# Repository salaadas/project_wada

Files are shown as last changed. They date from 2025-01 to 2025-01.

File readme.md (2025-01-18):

# Project Wada

Although I love my HHKB Pro 2, sometimes I just want some arrow keys for gaming. This made me learn how to design a PCB and make it has a layout somewhat similar to the HHKB. I also realized that the Realforce RC1 kinda has the same layout as this keyboard too.

Anyways, here is the layout.

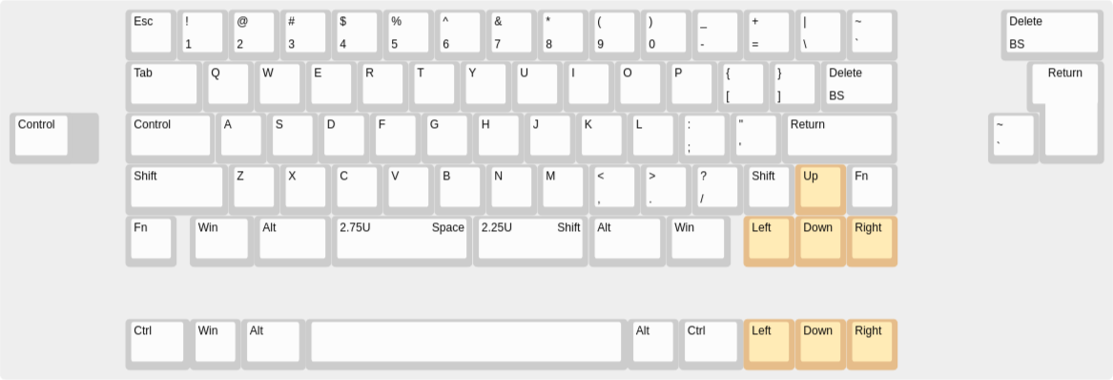
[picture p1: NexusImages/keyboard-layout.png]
keyboard layout


## Incomplete..... more to come after I finished!

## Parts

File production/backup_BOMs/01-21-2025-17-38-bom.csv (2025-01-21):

Designator | Footprint | Quantity | Value | LCSC Part #
BOOT_SW1, RESET_SW1 | SW_SPST_TL3342 | 2 | SW_SPST | C318884
C1, C10, C11, C9 | 603 | 4 | 1uF | C15849
C12, C13, C14, C15, C16, C17, C18, C19, C20, C23, C26, C29, C30, C31, C32, C33, C34, C35, C36, C37, C38, C39, C4, C40, C41, C42, C43, C44, C45, C46, C47, C5, C6, C7, C8 | 603 | 35 | 100nF | C14663
C2, C24, C27, C3 | 603 | 4 | 10uF | C19702
C21, C22 | 603 | 2 | 30pF | C1658
C25, C28 | CP_Elec_6.3x5.9 | 2 | 100uF | C134878
D1, D10, D11, D12, D13, D14, D15, D16, D17, D18, D19, D2, D20, D21, D22, D23, D24, D25, D26, D27, D28, D29, D3, D30, D31, D32, D33, D34, D35, D36, D37, D38, D39, D4, D40, D41, D42, D43, D44, D45, D46, D47, D48, D49, D5, D50, D51, D52, D53, D54, D55, D56, D57, D58, D59, D6, D60, D61, D62, D63, D64, D65, D66, D7, D8, D9 | D_SOD-123 | 66 | D_Small | C81598
F1 | 1206 | 1 | 500mA | C70076
J1 | USB_C_Receptacle_HRO_TYPE-C-31-M-12 | 1 | USB_C_Receptacle_USB2.0_16P | C165948
J2, J3 | JING 903-231A2031S10100 | 2 | USB_A | C42646
L1, L2, L3 | 603 | 3 | 220V @ 100MHz, 2A | C85832
LED1, LED10, LED11, LED12, LED13, LED14, LED15, LED16, LED2, LED3, LED4, LED5, LED6, LED7, LED8, LED9 | LED_SK6812MINI_HAND_SOLDER_3.5x3.5mm_P1.75mm | 16 | SK6812MINI | C2922787
R1, R2 | 402 | 2 | 5.1kR | C25905
R10, R11, R12, R14, R3, R4, R6, R7, R8, R9 | 603 | 10 | 10kR | C25804
R13 | 603 | 1 | 2.7kR | C13167
U1 | SOT-23 | 1 | XC6206PxxxMR | C5446
U2 | LQFP-48_7x7mm_P0.5mm | 1 | STM32F072C8T6 | C81720
U3 | SOIC-8_3.9x4.9mm_P1.27mm | 1 | MIC2026-2BN | C148072
U4 | LQFP-48_7x7mm_P0.5mm | 1 | FE1.1 | C28958
U5, U6, U7 | SOT-23-6-routable | 3 | SRV05-4 | C85364
U8 | SOT-23-5 | 1 | 74AHCT1G125 | C7484
Y1 | Crystal_SMD_3225-4pin_3.2x2.5mm | 1 | 12MHz | C9002

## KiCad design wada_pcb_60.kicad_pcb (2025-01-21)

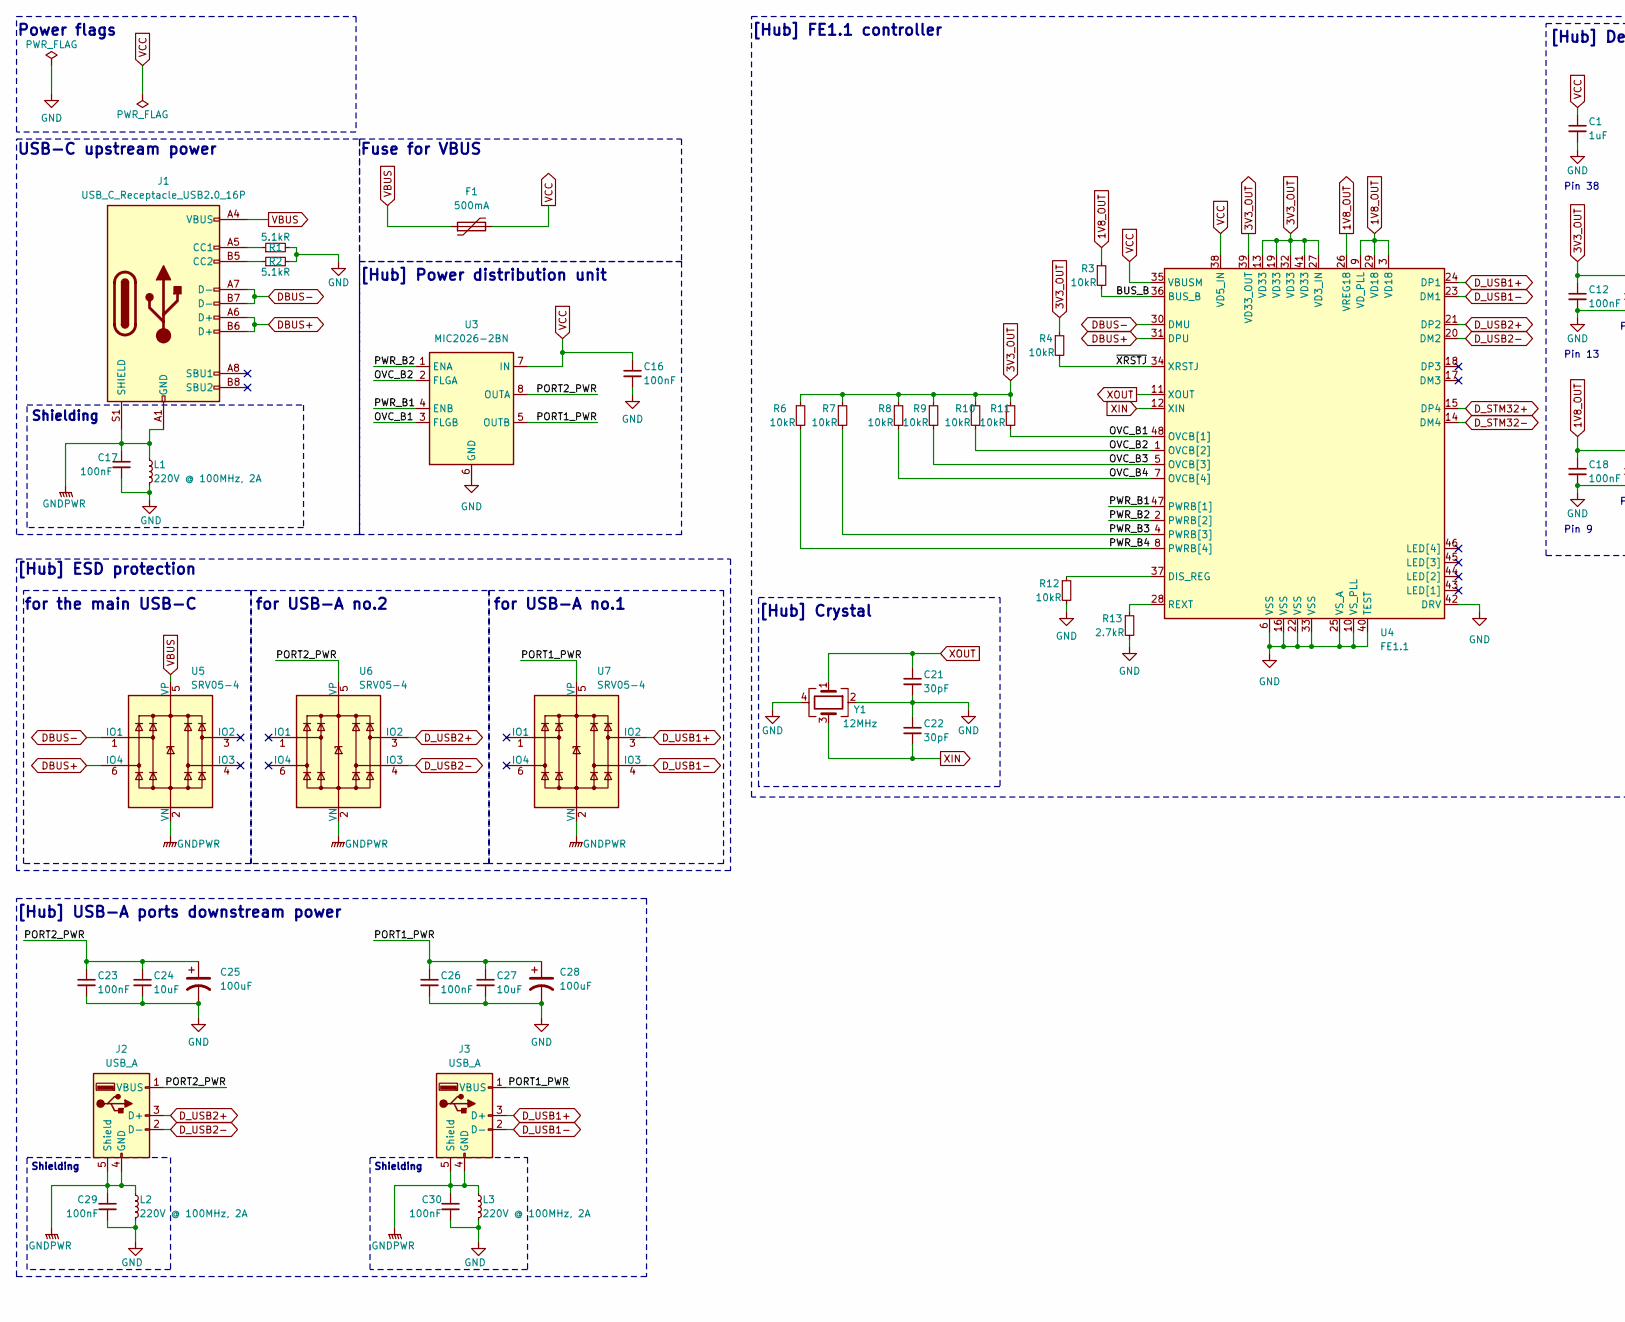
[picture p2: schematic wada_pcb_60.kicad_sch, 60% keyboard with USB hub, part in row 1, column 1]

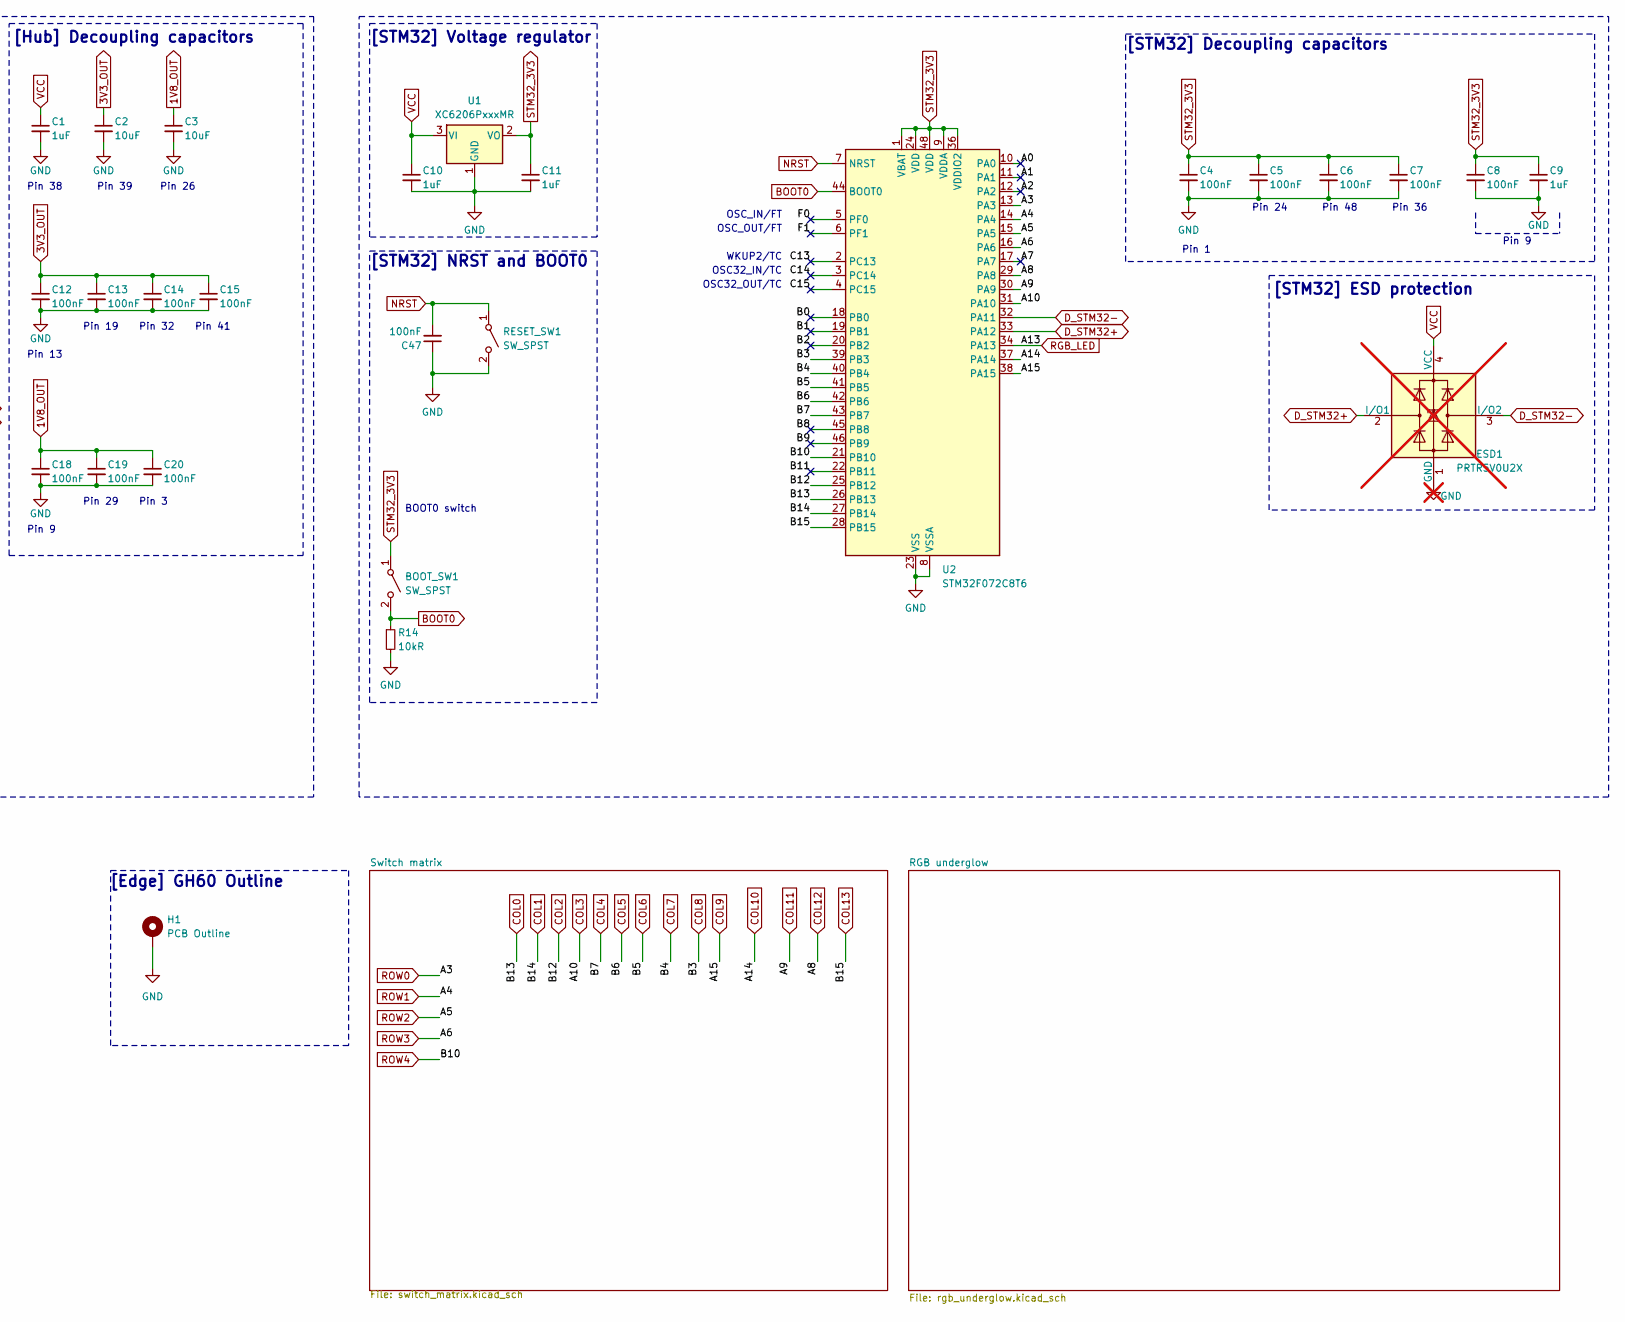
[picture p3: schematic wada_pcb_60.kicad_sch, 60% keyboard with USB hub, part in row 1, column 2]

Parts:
BOOT_SW1: SW_SPST; SW_SPST_TL3342
C1, C9, C10, C11: 1uF; C_0603_1608Metric
C2, C3, C24, C27: 10uF; C_0603_1608Metric
C4, C5, C6, C7, C8, C12, C13, C14, C15, C16, C17, C18, C19, C20, C23, C26, C29, C30, C47: 100nF; C_0603_1608Metric
C21, C22: 30pF; C_0603_1608Metric
C25, C28: 100uF; CP_Elec_6.3x5.9
ESD1: PRTR5V0U2X; SOT-143; not fitted
F1: 500mA; Fuse_1206_3216Metric
H1: PCB Outline; GH60_outline_without_bottom_mounting
J1: USB_C_Receptacle_USB2.0_16P; USB_C_Receptacle_HRO_TYPE-C-31-M-12
J2, J3: USB_A; JING 903-231A2031S10100
L1, L2, L3: 220V @ 100MHz, 2A; L_0603_1608Metric
R1, R2: 5.1kR; R_0402_1005Metric
R3, R4, R6, R7, R8, R9, R10, R11, R12, R14: 10kR; R_0603_1608Metric
R13: 2.7kR; R_0603_1608Metric
RESET_SW1: SW_SPST; SW_SPST_TL3342
U1: XC6206PxxxMR; SOT-23
U2: STM32F072C8T6; LQFP-48_7x7mm_P0.5mm
U3: MIC2026-2BN; SOIC-8_3.9x4.9mm_P1.27mm
U4: FE1.1; LQFP-48_7x7mm_P0.5mm
U5, U6, U7: SRV05-4; SOT-23-6-routable
Y1: 12MHz; Crystal_SMD_3225-4pin_3.2x2.5mm

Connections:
1V8_OUT: C3.1, C18.1, C19.1, C20.1, R3.1, U4.3 (VD18), U4.9 (VD_PLL), U4.26 (VREG18), U4.29 (VD18)
3V3_OUT: C2.1, C12.1, C13.1, C14.1, C15.1, R4.1, R6.1, R7.1, R8.1, R9.1, R10.1, R11.1, U4.13 (VD33), U4.19 (VD33), U4.27 (VD3_IN), U4.32 (VD33), U4.39 (VD33_OUT), U4.41 (VD33)
/A0: U2.10 (PA0)
/A1: U2.11 (PA1)
/A2: U2.12 (PA2)
/A7: U2.17 (PA7)
/B0: U2.18 (PB0)
/B1: U2.19 (PB1)
/B2: U2.20 (PB2)
/B8: U2.45 (PB8)
/B9: U2.46 (PB9)
/B11: U2.22 (PB11)
/BUS_B: R3.2, U4.36 (BUS_B)
/C13: U2.2 (PC13)
/C14: U2.3 (PC14)
/C15: U2.4 (PC15)
/F0: U2.5 (PF0)
/F1: U2.6 (PF1)
/OVC_B1: R11.2, U3.3 (FLGB), U4.48 (OVCB[1])
/OVC_B2: R10.2, U3.2 (FLGA), U4.1 (OVCB[2])
/OVC_B3: R9.2, U4.5 (OVCB[3])
/OVC_B4: R8.2, U4.7 (OVCB[4])
/PORT1_PWR: C26.1, C27.1, C28.1, J3.1 (VBUS), U3.5 (OUTB), U7.5 (VP)
/PORT2_PWR: C23.1, C24.1, C25.1, J2.1 (VBUS), U3.8 (OUTA), U6.5 (VP)
/PWR_B1: U3.4 (ENB), U4.47 (PWRB[1])
/PWR_B2: U3.1 (ENA), U4.2 (PWRB[2])
/PWR_B3: R7.2, U4.4 (PWRB[3])
/PWR_B4: R6.2, U4.8 (PWRB[4])
/~XRSTJ: R4.2, U4.34 (XRSTJ)
BOOT0: BOOT_SW1.2 (B), R14.1, U2.44 (BOOT0)
COL0: U2.26 (PB13); also elsewhere on the board
COL1: U2.27 (PB14); also elsewhere on the board
COL2: U2.25 (PB12); also elsewhere on the board
COL3: U2.31 (PA10); also elsewhere on the board
COL4: U2.43 (PB7); also elsewhere on the board
COL5: U2.42 (PB6); also elsewhere on the board
COL6: U2.41 (PB5); also elsewhere on the board
COL7: U2.40 (PB4); also elsewhere on the board
COL8: U2.39 (PB3); also elsewhere on the board
COL9: U2.38 (PA15); also elsewhere on the board
COL10: U2.37 (PA14); also elsewhere on the board
COL11: U2.30 (PA9); also elsewhere on the board
COL12: U2.29 (PA8); also elsewhere on the board
COL13: U2.28 (PB15); also elsewhere on the board
DBUS+: J1.A6 (D+), J1.B6 (D+), U4.31 (DPU), U5.6 (IO4)
DBUS-: J1.A7 (D-), J1.B7 (D-), U4.30 (DMU), U5.1 (IO1)
D_STM32+: ESD1.2 (I/O1), U2.33 (PA12), U4.15 (DP4)
D_STM32-: ESD1.3 (I/O2), U2.32 (PA11), U4.14 (DM4)
D_USB1+: J3.3 (D+), U4.24 (DP1), U7.3 (IO2)
D_USB1-: J3.2 (D-), U4.23 (DM1), U7.4 (IO3)
D_USB2+: J2.3 (D+), U4.21 (DP2), U6.3 (IO2)
D_USB2-: J2.2 (D-), U4.20 (DM2), U6.4 (IO3)
GND: C1.2, C2.2, C3.2, C4.2, C5.2, C6.2, C7.2, C8.2, C9.2, C10.2, C11.2, C12.2, C13.2, C14.2, C15.2, C16.2, C17.2, C18.2, C19.2, C20.2, C21.2, C22.1, C23.2, C24.2, C25.2, C26.2, C27.2, C28.2, C29.2, C30.2, C47.1, ESD1.1 (GND), H1.1, L1.2, L2.2, L3.2, R1.2, R2.2, R12.2, R13.2, R14.2, RESET_SW1.2 (B), U1.1 (GND), U2.8 (VSSA), U2.23 (VSS), U2.35 (VSS), U2.47 (VSS), U3.6 (GND), U4.6 (VSS), U4.10 (VS_PLL), U4.16 (VSS), U4.22 (VSS), U4.25 (VS_A), U4.33 (VSS), U4.40 (TEST), U4.42 (DRV), Y1.2, Y1.4; also elsewhere on the board
GNDPWR: C17.1, C29.1, C30.1, J1.A1 (GND), J1.A12 (GND), J1.B1 (GND), J1.B12 (GND), J1.S1 (SHIELD), J2.4 (GND), J2.5 (Shield), J3.4 (GND), J3.5 (Shield), L1.1, L2.1, L3.1, U5.2 (VN), U6.2 (VN), U7.2 (VN)
NRST: C47.2, RESET_SW1.1 (A), U2.7 (NRST)
unnamed: J1.A5 (CC1), R1.1
unnamed: J1.B5 (CC2), R2.1
unnamed: R12.1, U4.37 (DIS_REG)
unnamed: R13.1, U4.28 (REXT)
RGB_LED: U2.34 (PA13); also elsewhere on the board
ROW0: U2.13 (PA3); also elsewhere on the board
ROW1: U2.14 (PA4); also elsewhere on the board
ROW2: U2.15 (PA5); also elsewhere on the board
ROW3: U2.16 (PA6); also elsewhere on the board
ROW4: U2.21 (PB10); also elsewhere on the board
STM32_3V3: BOOT_SW1.1 (A), C4.1, C5.1, C6.1, C7.1, C8.1, C9.1, C11.1, U1.2 (VO), U2.1 (VBAT), U2.9 (VDDA), U2.24 (VDD), U2.36 (VDDIO2), U2.48 (VDD)
VBUS: F1.1, J1.A4 (VBUS), J1.A9 (VBUS), J1.B4 (VBUS), J1.B9 (VBUS), U5.5 (VP)
VCC: C1.1, C10.1, C16.1, ESD1.4 (VCC), F1.2, U1.3 (VI), U3.7 (IN), U4.35 (VBUSM), U4.38 (VD5_IN); also elsewhere on the board
XIN: C22.2, U4.12 (XIN), Y1.3
XOUT: C21.1, U4.11 (XOUT), Y1.1

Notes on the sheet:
for USB-A no.1
Shielding
[Hub] ESD protection
Pin 24
Pin 32
Pin 9
USB-C upstream power
OSC_OUT/FT
OSC32_OUT/TC
Pin 29
Pin 26
OSC32_IN/TC
Pin 3
Pin 38
[Hub] USB-A ports downstream power
OSC_IN/FT
[Edge] GH60 Outline
[STM32] ESD protection
Fuse for VBUS
[Hub] Decoupling capacitors
WKUP2/TC
Pin 36
Pin 39
Pin 48
[STM32] Voltage regulator
Pin 19
Pin 41
for USB-A no.2
Power flags
[Hub] Power distribution unit
Pin 1
for the main USB-C
[STM32] Decoupling capacitors
[STM32] NRST and BOOT0
[Hub] FE1.1 controller
[Hub] Crystal
Pin 13
BOOT0 switch

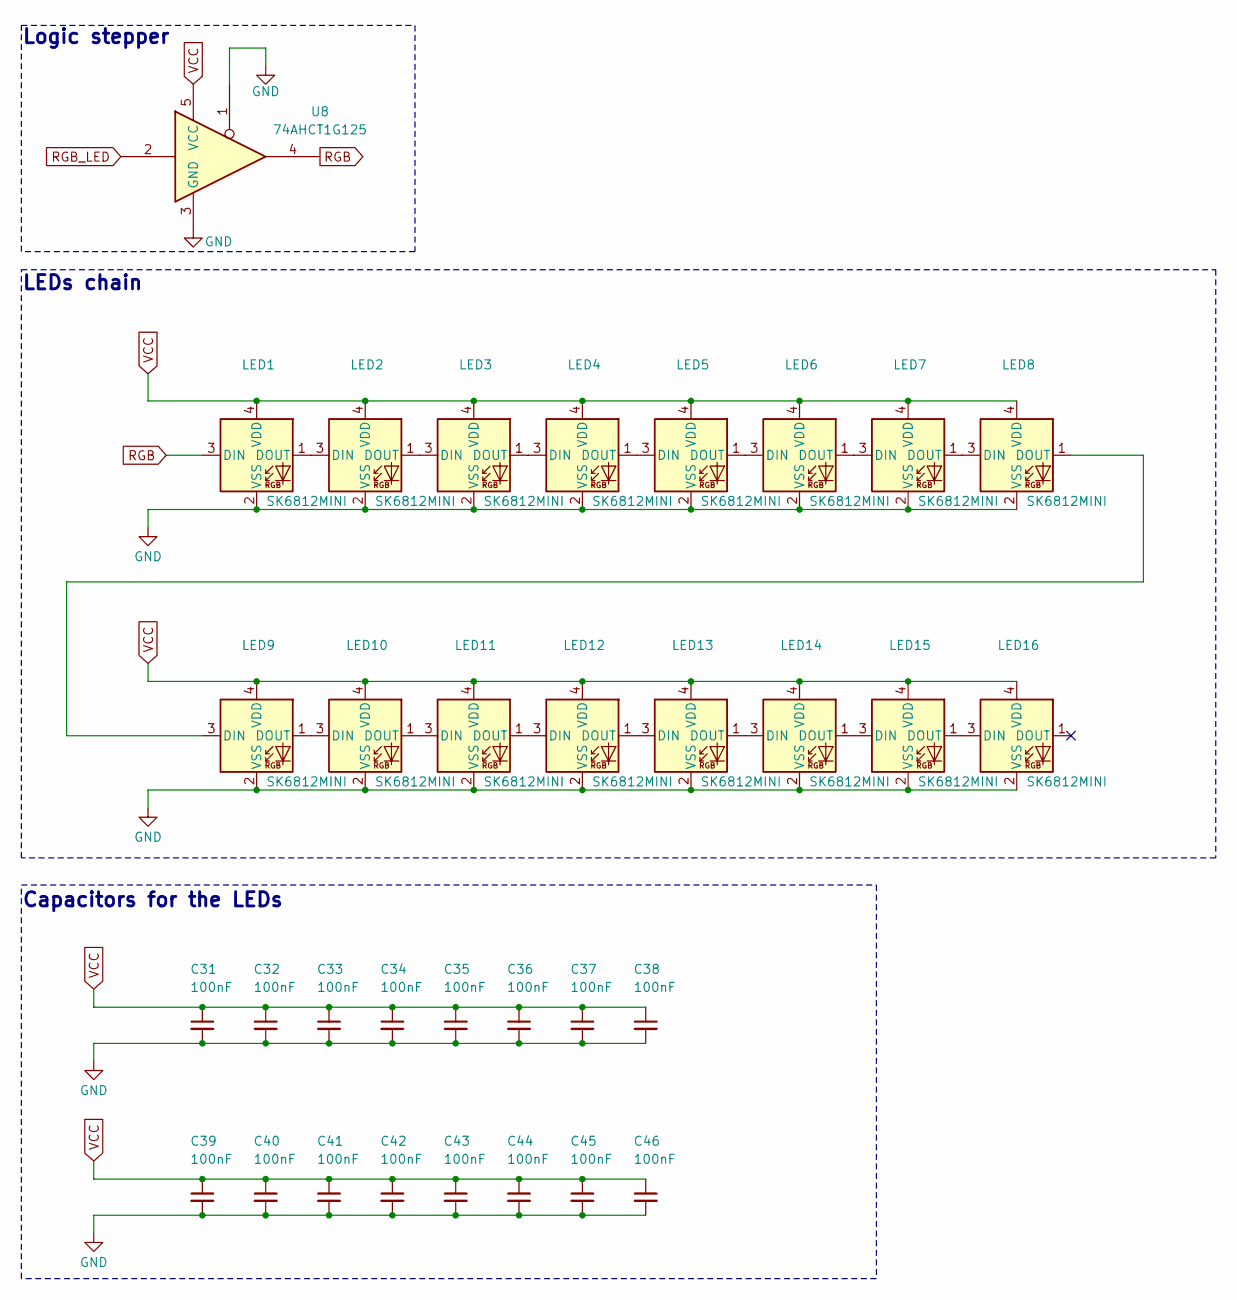
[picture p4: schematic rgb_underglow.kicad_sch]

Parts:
C31, C32, C33, C34, C35, C36, C37, C38, C39, C40, C41, C42, C43, C44, C45, C46: 100nF; C_0603_1608Metric
LED1, LED2, LED3, LED4, LED5, LED6, LED7, LED8, LED9, LED10, LED11, LED12, LED13, LED14, LED15, LED16: SK6812MINI; LED_SK6812MINI_HAND_SOLDER_3.5x3.5mm_P1.75mm
U8: 74AHCT1G125; SOT-23-5

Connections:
GND: C31.2, C32.2, C33.2, C34.2, C35.2, C36.2, C37.2, C38.2, C39.2, C40.2, C41.2, C42.2, C43.2, C44.2, C45.2, C46.2, LED1.2 (VSS), LED2.2 (VSS), LED3.2 (VSS), LED4.2 (VSS), LED5.2 (VSS), LED6.2 (VSS), LED7.2 (VSS), LED8.2 (VSS), LED9.2 (VSS), LED10.2 (VSS), LED11.2 (VSS), LED12.2 (VSS), LED13.2 (VSS), LED14.2 (VSS), LED15.2 (VSS), LED16.2 (VSS), U8.1, U8.3 (GND); also elsewhere on the board
unnamed: LED1.1 (DOUT), LED2.3 (DIN)
unnamed: LED2.1 (DOUT), LED3.3 (DIN)
unnamed: LED3.1 (DOUT), LED4.3 (DIN)
unnamed: LED4.1 (DOUT), LED5.3 (DIN)
unnamed: LED5.1 (DOUT), LED6.3 (DIN)
unnamed: LED6.1 (DOUT), LED7.3 (DIN)
unnamed: LED7.1 (DOUT), LED8.3 (DIN)
unnamed: LED8.1 (DOUT), LED9.3 (DIN)
unnamed: LED9.1 (DOUT), LED10.3 (DIN)
unnamed: LED10.1 (DOUT), LED11.3 (DIN)
unnamed: LED11.1 (DOUT), LED12.3 (DIN)
unnamed: LED12.1 (DOUT), LED13.3 (DIN)
unnamed: LED13.1 (DOUT), LED14.3 (DIN)
unnamed: LED14.1 (DOUT), LED15.3 (DIN)
unnamed: LED15.1 (DOUT), LED16.3 (DIN)
RGB: LED1.3 (DIN), U8.4
RGB_LED: U8.2; also elsewhere on the board
VCC: C31.1, C32.1, C33.1, C34.1, C35.1, C36.1, C37.1, C38.1, C39.1, C40.1, C41.1, C42.1, C43.1, C44.1, C45.1, C46.1, LED1.4 (VDD), LED2.4 (VDD), LED3.4 (VDD), LED4.4 (VDD), LED5.4 (VDD), LED6.4 (VDD), LED7.4 (VDD), LED8.4 (VDD), LED9.4 (VDD), LED10.4 (VDD), LED11.4 (VDD), LED12.4 (VDD), LED13.4 (VDD), LED14.4 (VDD), LED15.4 (VDD), LED16.4 (VDD), U8.5 (VCC); also elsewhere on the board

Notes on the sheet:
LEDs chain
Logic stepper
Capacitors for the LEDs

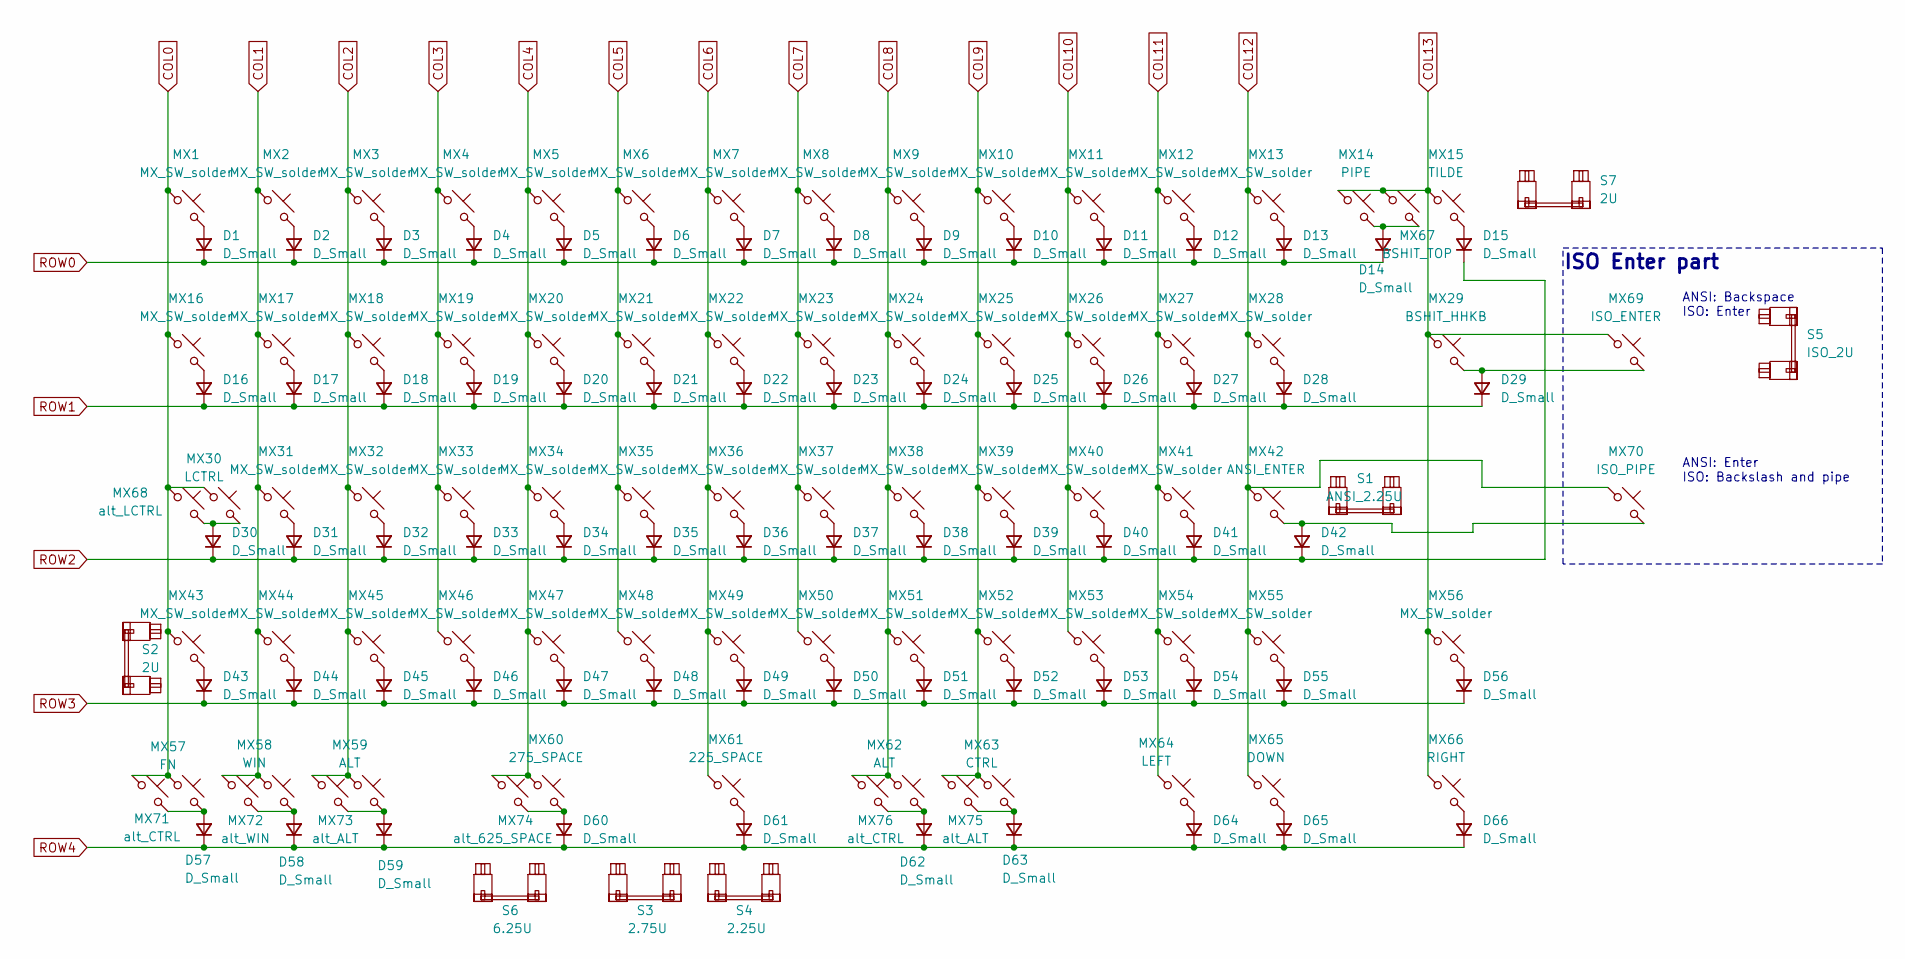
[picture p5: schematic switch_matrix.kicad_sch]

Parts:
D1, D2, D3, D4, D5, D6, D7, D8, D9, D10, D11, D12, D13, D14, D15, D16, D17, D18, D19, D20, D21, D22, D23, D24, D25, D26, D27, D28, D29, D30, D31, D32, D33, D34, D35, D36, D37, D38, D39, D40, D41, D42, D43, D44, D45, D46, D47, D48, D49, D50, D51, D52, D53, D54, D55, D56, D57, D58, D59, D60, D61, D62, D63, D64, D65, D66: D_Small; D_SOD-123
MX1, MX2, MX3, MX4, MX5, MX6, MX7, MX8, MX9, MX10, MX11, MX12, MX13, MX17, MX18, MX19, MX20, MX21, MX22, MX23, MX24, MX25, MX26, MX27, MX28, MX31, MX32, MX33, MX34, MX35, MX36, MX37, MX38, MX39, MX40, MX41, MX43, MX44, MX45, MX46, MX47, MX48, MX49, MX50, MX51, MX52, MX53, MX54, MX55, MX56: MX_SW_solder; SW_MX_1u
MX14: PIPE; SW_MX_1u
MX15: TILDE; SW_MX_1u
MX16: MX_SW_solder; SW_MX_1.5u
MX29: BSHIT_HHKB; SW_MX_1.5u
MX30: LCTRL; SW_MX_1.75u
MX42: ANSI_ENTER; SW_MX_1u
MX57: FN; SW_MX_1u
MX58: WIN; SW_MX_1.25u
MX59, MX62: ALT; SW_MX_1.5u
MX60: 275_SPACE; SW_MX_1u
MX61: 225_SPACE; SW_MX_1u
MX63: CTRL; SW_MX_1.25u
MX64: LEFT; SW_MX_1u
MX65: DOWN; SW_MX_1u
MX66: RIGHT; SW_MX_1u
MX67: BSHIT_TOP; SW_MX_1u
MX68: alt_LCTRL; SW_MX_1.75u_STP_1.25
MX69: ISO_ENTER; SW_MX_1u
MX70: ISO_PIPE; SW_MX_1u
MX71: alt_CTRL; SW_MX_1.25u
MX72: alt_WIN; SW_MX_1u
MX73, MX75: alt_ALT; SW_MX_1.25u
MX74: alt_625_SPACE; SW_MX_1u
MX76: alt_CTRL; SW_MX_1u
S1: ANSI_2.25U; STAB_MX_2.25u
S2: 2U; STAB_MX_P_2u
S3: 2.75U; STAB_MX_P_2.75u
S4: 2.25U; STAB_MX_P_2.25u
S5: ISO_2U; STAB_MX_ISO-ROT
S6: 6.25U; STAB_MX_P_6.25u
S7: 2U; STAB_MX_2u

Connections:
COL0: MX1.1, MX16.1, MX30.1, MX43.1, MX57.1, MX68.1, MX71.1; also elsewhere on the board
COL1: MX2.1, MX17.1, MX31.1, MX44.1, MX58.1, MX72.1; also elsewhere on the board
COL2: MX3.1, MX18.1, MX32.1, MX45.1, MX59.1, MX73.1; also elsewhere on the board
COL3: MX4.1, MX19.1, MX33.1, MX46.1; also elsewhere on the board
COL4: MX5.1, MX20.1, MX34.1, MX47.1, MX60.1, MX74.1; also elsewhere on the board
COL5: MX6.1, MX21.1, MX35.1, MX48.1; also elsewhere on the board
COL6: MX7.1, MX22.1, MX36.1, MX49.1, MX61.1; also elsewhere on the board
COL7: MX8.1, MX23.1, MX37.1, MX50.1; also elsewhere on the board
COL8: MX9.1, MX24.1, MX38.1, MX51.1, MX62.1, MX76.1; also elsewhere on the board
COL9: MX10.1, MX25.1, MX39.1, MX52.1, MX63.1, MX75.1; also elsewhere on the board
COL10: MX11.1, MX26.1, MX40.1, MX53.1; also elsewhere on the board
COL11: MX12.1, MX27.1, MX41.1, MX54.1, MX64.1; also elsewhere on the board
COL12: MX13.1, MX28.1, MX42.1, MX55.1, MX65.1, MX70.1; also elsewhere on the board
COL13: MX14.1, MX15.1, MX29.1, MX56.1, MX66.1, MX67.1, MX69.1; also elsewhere on the board
unnamed: D1.2 (A), MX1.2
unnamed: D2.2 (A), MX2.2
unnamed: D3.2 (A), MX3.2
unnamed: D4.2 (A), MX4.2
unnamed: D5.2 (A), MX5.2
unnamed: D6.2 (A), MX6.2
unnamed: D7.2 (A), MX7.2
unnamed: D8.2 (A), MX8.2
unnamed: D9.2 (A), MX9.2
unnamed: D10.2 (A), MX10.2
unnamed: D11.2 (A), MX11.2
unnamed: D12.2 (A), MX12.2
unnamed: D13.2 (A), MX13.2
unnamed: D14.2 (A), MX14.2, MX67.2
unnamed: D15.2 (A), MX15.2
unnamed: D16.2 (A), MX16.2
unnamed: D17.2 (A), MX17.2
unnamed: D18.2 (A), MX18.2
unnamed: D19.2 (A), MX19.2
unnamed: D20.2 (A), MX20.2
unnamed: D21.2 (A), MX21.2
unnamed: D22.2 (A), MX22.2
unnamed: D23.2 (A), MX23.2
unnamed: D24.2 (A), MX24.2
unnamed: D25.2 (A), MX25.2
unnamed: D26.2 (A), MX26.2
unnamed: D27.2 (A), MX27.2
unnamed: D28.2 (A), MX28.2
unnamed: D29.2 (A), MX29.2, MX69.2
unnamed: D30.2 (A), MX30.2, MX68.2
unnamed: D31.2 (A), MX31.2
unnamed: D32.2 (A), MX32.2
unnamed: D33.2 (A), MX33.2
unnamed: D34.2 (A), MX34.2
unnamed: D35.2 (A), MX35.2
unnamed: D36.2 (A), MX36.2
unnamed: D37.2 (A), MX37.2
unnamed: D38.2 (A), MX38.2
unnamed: D39.2 (A), MX39.2
unnamed: D40.2 (A), MX40.2
unnamed: D41.2 (A), MX41.2
unnamed: D42.2 (A), MX42.2, MX70.2
unnamed: D43.2 (A), MX43.2
unnamed: D44.2 (A), MX44.2
unnamed: D45.2 (A), MX45.2
unnamed: D46.2 (A), MX46.2
unnamed: D47.2 (A), MX47.2
unnamed: D48.2 (A), MX48.2
unnamed: D49.2 (A), MX49.2
unnamed: D50.2 (A), MX50.2
unnamed: D51.2 (A), MX51.2
unnamed: D52.2 (A), MX52.2
unnamed: D53.2 (A), MX53.2
unnamed: D54.2 (A), MX54.2
unnamed: D55.2 (A), MX55.2
unnamed: D56.2 (A), MX56.2
unnamed: D57.2 (A), MX57.2, MX71.2
unnamed: D58.2 (A), MX58.2, MX72.2
unnamed: D59.2 (A), MX59.2, MX73.2
unnamed: D60.2 (A), MX60.2, MX74.2
unnamed: D61.2 (A), MX61.2
unnamed: D62.2 (A), MX62.2, MX76.2
unnamed: D63.2 (A), MX63.2, MX75.2
unnamed: D64.2 (A), MX64.2
unnamed: D65.2 (A), MX65.2
unnamed: D66.2 (A), MX66.2
ROW0: D1.1 (K), D2.1 (K), D3.1 (K), D4.1 (K), D5.1 (K), D6.1 (K), D7.1 (K), D8.1 (K), D9.1 (K), D10.1 (K), D11.1 (K), D12.1 (K), D13.1 (K), D14.1 (K); also elsewhere on the board
ROW1: D16.1 (K), D17.1 (K), D18.1 (K), D19.1 (K), D20.1 (K), D21.1 (K), D22.1 (K), D23.1 (K), D24.1 (K), D25.1 (K), D26.1 (K), D27.1 (K), D28.1 (K), D29.1 (K); also elsewhere on the board
ROW2: D15.1 (K), D30.1 (K), D31.1 (K), D32.1 (K), D33.1 (K), D34.1 (K), D35.1 (K), D36.1 (K), D37.1 (K), D38.1 (K), D39.1 (K), D40.1 (K), D41.1 (K), D42.1 (K); also elsewhere on the board
ROW3: D43.1 (K), D44.1 (K), D45.1 (K), D46.1 (K), D47.1 (K), D48.1 (K), D49.1 (K), D50.1 (K), D51.1 (K), D52.1 (K), D53.1 (K), D54.1 (K), D55.1 (K), D56.1 (K); also elsewhere on the board
ROW4: D57.1 (K), D58.1 (K), D59.1 (K), D60.1 (K), D61.1 (K), D62.1 (K), D63.1 (K), D64.1 (K), D65.1 (K), D66.1 (K); also elsewhere on the board

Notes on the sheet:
ANSI: Backspace ISO: Enter
ISO Enter part
ANSI: Enter ISO: Backslash and pipe

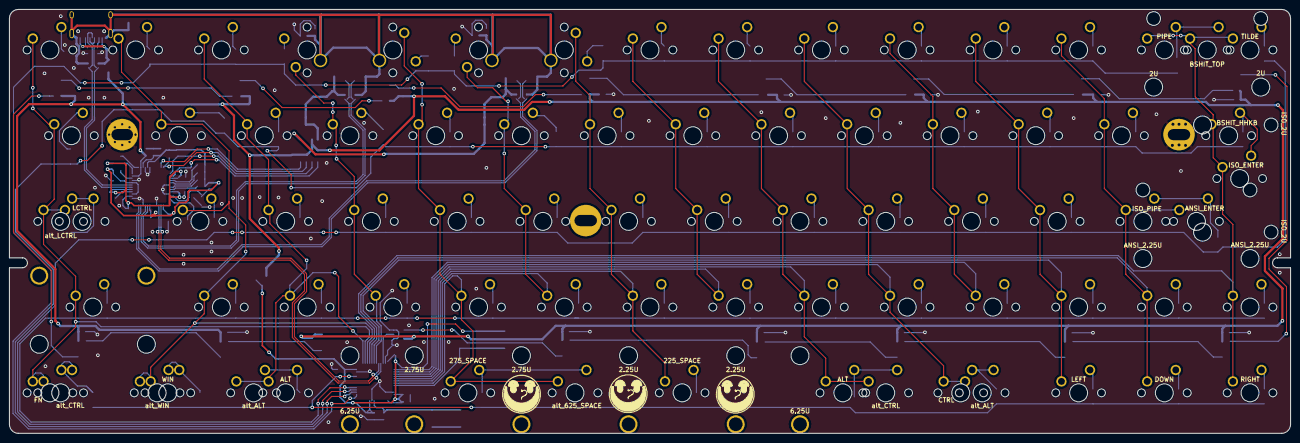
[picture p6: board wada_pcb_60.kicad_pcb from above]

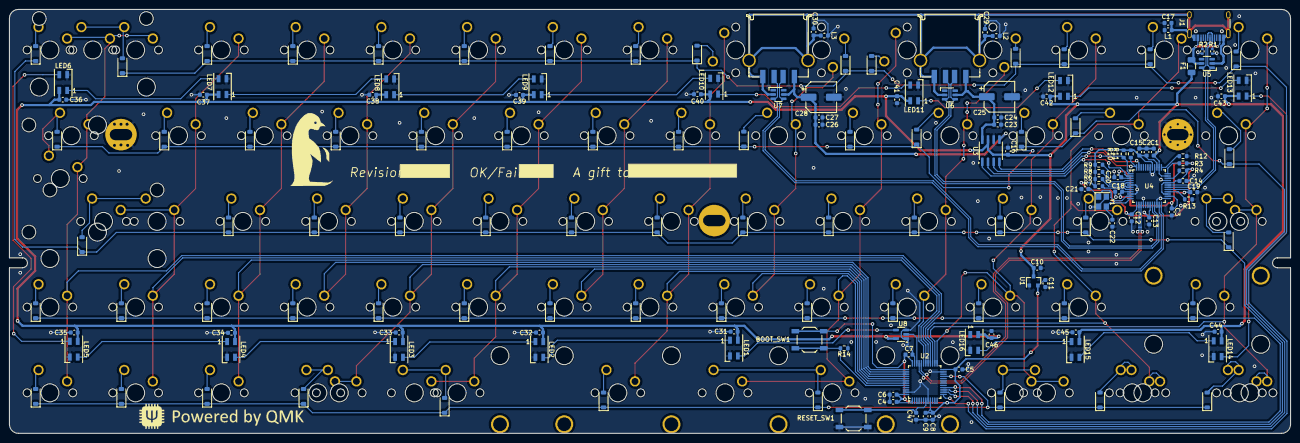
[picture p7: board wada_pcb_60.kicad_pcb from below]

Board: 2 copper layers, 284.7 x 94.2 mm, 244 parts (160 on the bottom side), 137 nets.

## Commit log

2025-01-18 subversion to fucking git
    [rgb_underglow.kicad_sch, switch_matrix.kicad_sch, wada_pcb_60.kicad_pcb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]
2025-01-19 wired up the LEDS, rows, and columns!
    [wada_pcb_60.kicad_pcb, wada_pcb_60.kicad_sch]
2025-01-20 done! missing the reset switch!
    [wada_pcb_60.kicad_pcb, wada_pcb_60.kicad_sch]
2025-01-20 review time!
    [wada_pcb_60.kicad_pcb, wada_pcb_60.kicad_sch]
2025-01-21 Changed USB type-A and LED parts
    [bom.csv, designators.csv, positions.csv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]
2025-01-21 checking phase
    [01-21-2025-17-38-bom.csv, 01-21-2025-orig-bom.csv, designators.csv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]
